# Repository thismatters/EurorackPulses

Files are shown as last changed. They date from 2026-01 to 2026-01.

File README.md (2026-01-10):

# Pulses Expander (for Turing Machine)

The circuit here is a direct copy of the [Music Thing Modular Volts Expander](https://github.com/TomWhitwell/Turing-Pulse-Expander).

The KiCAD project here uses the library/footprints [found in my companion repo](https://github.com/thismatters/EurorackKiCAD).

## Width

6hp

## Inputs

The back of the module has a connection for the `pulses` output from the Turing Machine.

## Outputs

11 jacks which pulse along with the bits (and combinations thereof) on the Turing Machine.

## Vendors

There are part numbers in the [BOM](tm-pulses.csv) for many of the parts (not for basic passives though) at the following vendors:

* [Mouser](https://www.mouser.com): Needs no introduction. Get your ICs from here (or [digikey](https://www.digikey.com)).
* [Tayda Electronics](https://www.taydaelectronics.com/): Good supplier for passive components; audio jacks, and potentiometers. Their audio jacks are slightly smaller than the thonkiconn from thonk.
* [Love My Switches](https://lovemyswitches.com/): Has [really good knobs](https://lovemyswitches.com/anodized-aluminum-knob-the-lo-fi-1-4-smooth-shaft-12-5mm-od/) to go on those potentiometers!
* [OSHPark](https://oshpark.com/): Fast and (relatively) cheap PCB manufacturer. Prototype run pending.

## Changelog

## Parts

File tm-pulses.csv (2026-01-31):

# | Reference | Qty | Value | Footprint | DNP | Vendor | PartNum | Note
1 | D1, D2, D3, D4, D5, D6, D7, D8, D9, D10, D11 | 11 | LED_GREEN | LED_THT:LED_D3.0mm
2 | J1 | 1 | Conn_02x08_Odd_Even | Eurorack:PinHeader_2x08_P2.54mm_Vertical |  | Tayda | A-2956
3 | J2 | 1 | OUT1 | Eurorack:AudioJack2_Tayda_A-2566 |  | Tayda | A-2566
4 | J3 | 1 | OUT2 | Eurorack:AudioJack2_Tayda_A-2566 |  | Tayda | A-2566
5 | J4 | 1 | OUT3 | Eurorack:AudioJack2_Tayda_A-2566 |  | Tayda | A-2566
6 | J5 | 1 | OUT4 | Eurorack:AudioJack2_Tayda_A-2566 |  | Tayda | A-2566
7 | J6 | 1 | OUT5 | Eurorack:AudioJack2_Tayda_A-2566 |  | Tayda | A-2566
8 | J7 | 1 | OUT6 | Eurorack:AudioJack2_Tayda_A-2566 |  | Tayda | A-2566
9 | J8 | 1 | OUT7 | Eurorack:AudioJack2_Tayda_A-2566 |  | Tayda | A-2566
10 | J9 | 1 | OUT12 | Eurorack:AudioJack2_Tayda_A-2566 |  | Tayda | A-2566
11 | J10 | 1 | OUT24 | Eurorack:AudioJack2_Tayda_A-2566 |  | Tayda | A-2566
12 | J11 | 1 | OUT47 | Eurorack:AudioJack2_Tayda_A-2566 |  | Tayda | A-2566
13 | J12 | 1 | OUT1247 | Eurorack:AudioJack2_Tayda_A-2566 |  | Tayda | A-2566
14 | R1, R3, R5, R7, R9, R11, R13, R15, R17, R19, R21 | 11 | 1K | Resistor_SMD:R_0805_2012Metric
15 | R2, R4, R6, R8, R10, R12, R14, R16, R18, R20, R22 | 11 | 2K | Resistor_SMD:R_0805_2012Metric
16 | U1 | 1 | 4081 | Package_SO:TSSOP-14_4.4x5mm_P0.65mm |  | Mouser | 595-CD4081BPWR

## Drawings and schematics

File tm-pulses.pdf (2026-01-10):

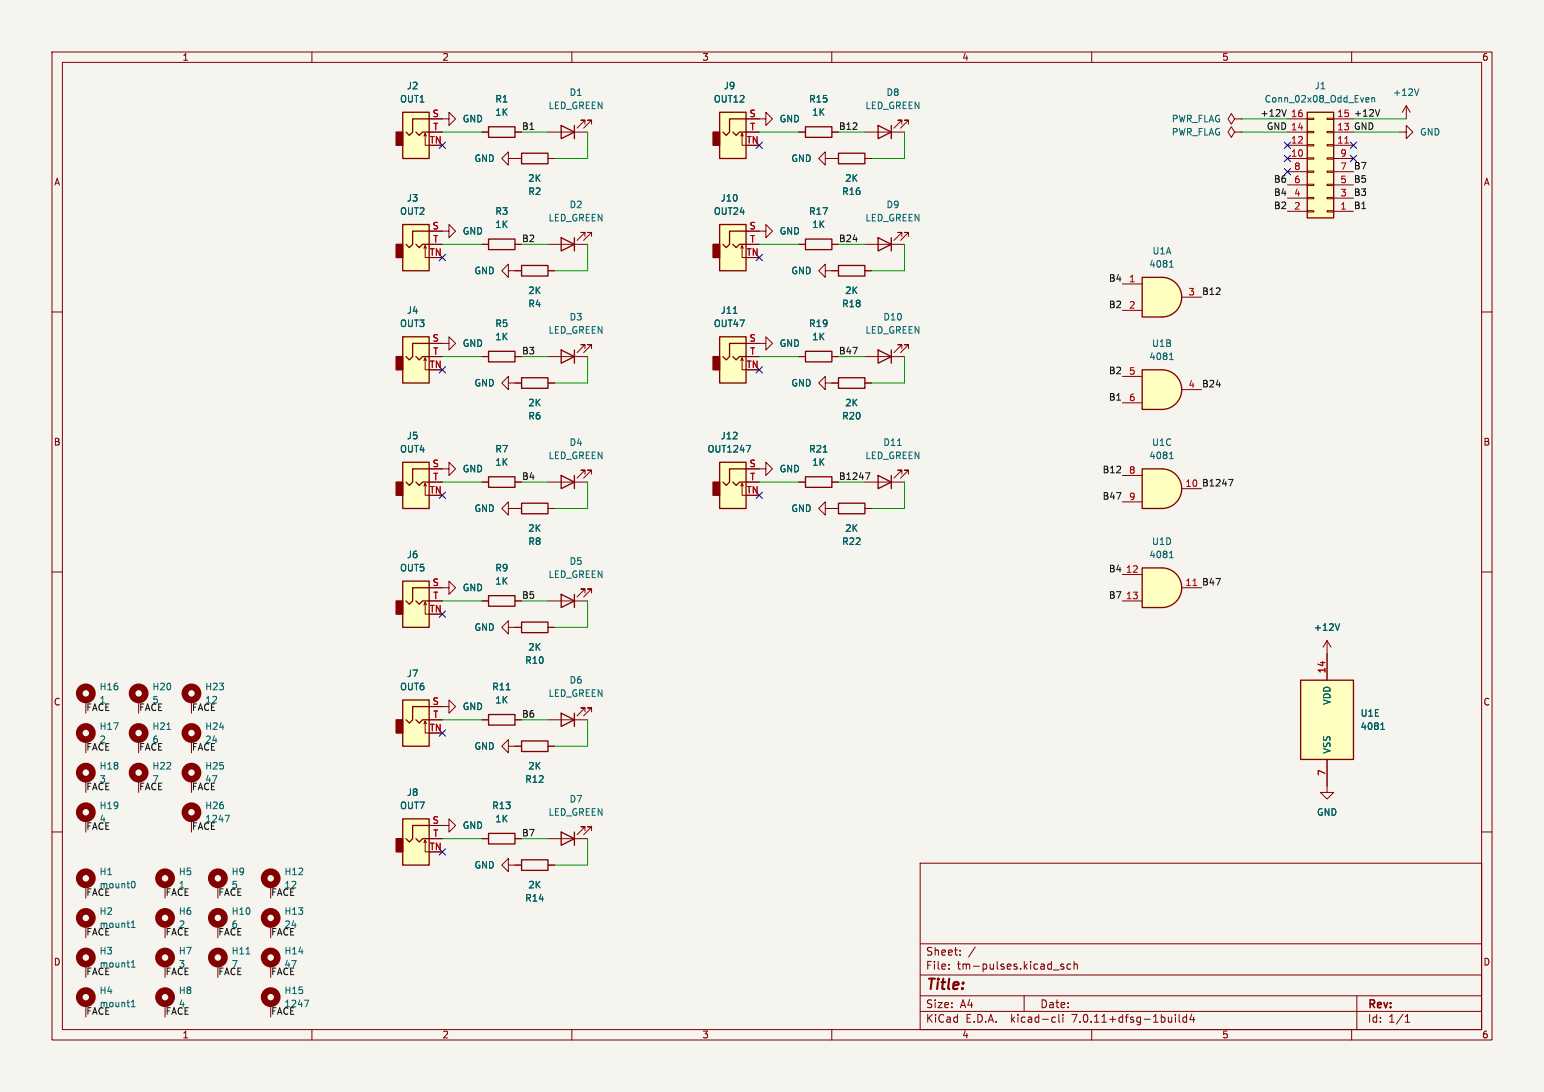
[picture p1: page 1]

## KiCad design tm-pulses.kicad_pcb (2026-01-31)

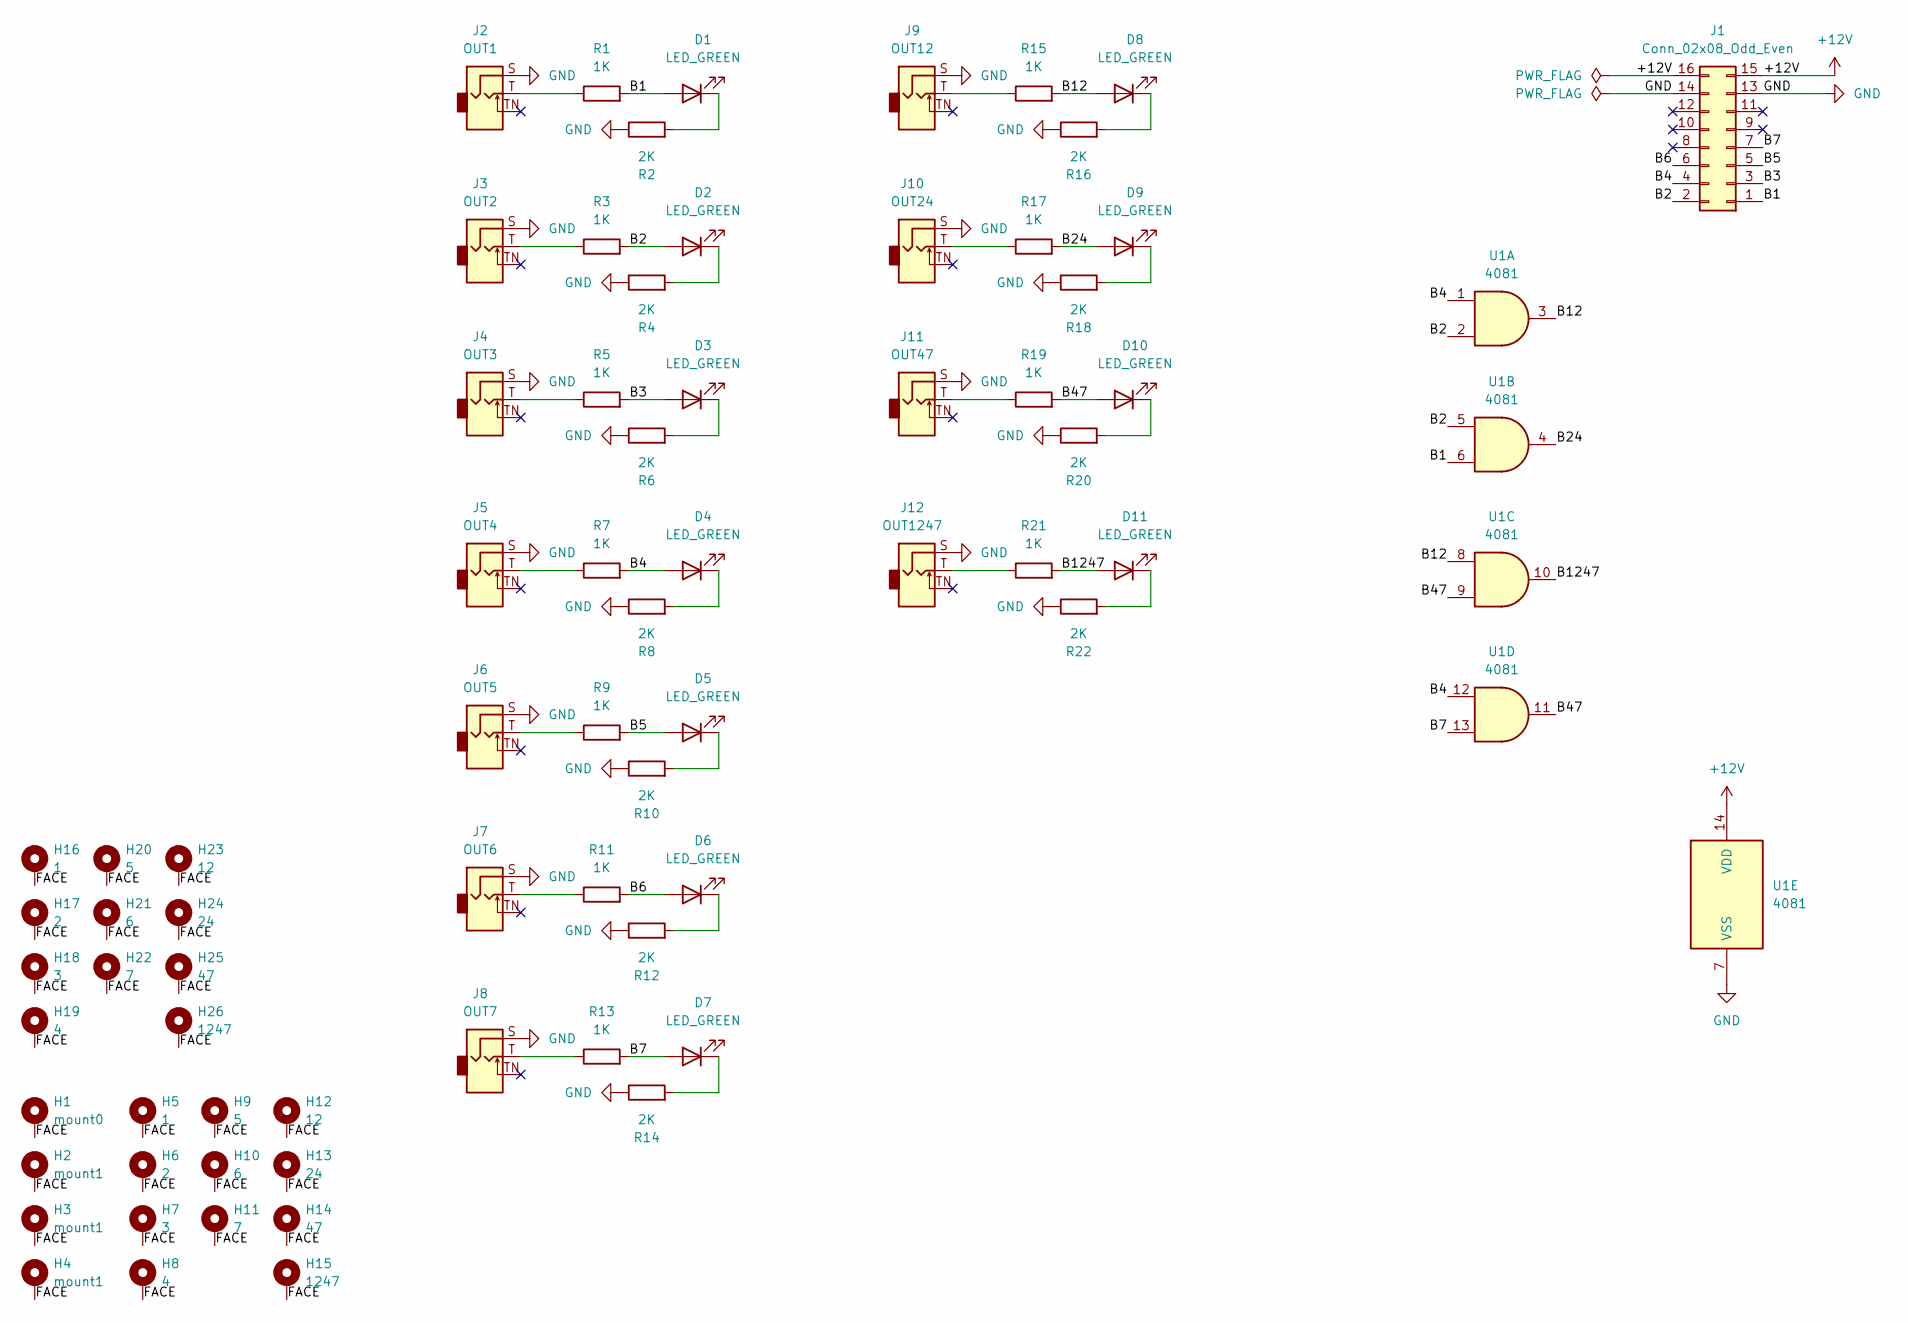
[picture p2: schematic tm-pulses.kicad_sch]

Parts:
D1, D2, D3, D4, D5, D6, D7, D8, D9, D10, D11: LED_GREEN; LED_D3.0mm
H1: mount0; Mech-MountingHole
H2, H3, H4: mount1; Mech-MountingHole
H5: 1; Mech-AudioJack-Hole-Output-Gate
H6: 2; Mech-AudioJack-Hole-Output-Gate
H7: 3; Mech-AudioJack-Hole-Output-Gate
H8: 4; Mech-AudioJack-Hole-Output-Gate
H9: 5; Mech-AudioJack-Hole-Output-Gate
H10: 6; Mech-AudioJack-Hole-Output-Gate
H11: 7; Mech-AudioJack-Hole-Output-Gate
H12: 12; Mech-AudioJack-Hole-Output-Gate
H13: 24; Mech-AudioJack-Hole-Output-Gate
H14: 47; Mech-AudioJack-Hole-Output-Gate
H15: 1247; Mech-AudioJack-Hole-Output-Gate
H16: 1; Mech-LED-Hole-3mm
H17: 2; Mech-LED-Hole-3mm
H18: 3; Mech-LED-Hole-3mm
H19: 4; Mech-LED-Hole-3mm
H20: 5; Mech-LED-Hole-3mm
H21: 6; Mech-LED-Hole-3mm
H22: 7; Mech-LED-Hole-3mm
H23: 12; Mech-LED-Hole-3mm
H24: 24; Mech-LED-Hole-3mm
H25: 47; Mech-LED-Hole-3mm
H26: 1247; Mech-LED-Hole-3mm
J1: Conn_02x08_Odd_Even; PinHeader_2x08_P2.54mm_Vertical; PartNum A-2956
J2: OUT1; AudioJack2_Tayda_A-2566; PartNum A-2566
J3: OUT2; AudioJack2_Tayda_A-2566; PartNum A-2566
J4: OUT3; AudioJack2_Tayda_A-2566; PartNum A-2566
J5: OUT4; AudioJack2_Tayda_A-2566; PartNum A-2566
J6: OUT5; AudioJack2_Tayda_A-2566; PartNum A-2566
J7: OUT6; AudioJack2_Tayda_A-2566; PartNum A-2566
J8: OUT7; AudioJack2_Tayda_A-2566; PartNum A-2566
J9: OUT12; AudioJack2_Tayda_A-2566; PartNum A-2566
J10: OUT24; AudioJack2_Tayda_A-2566; PartNum A-2566
J11: OUT47; AudioJack2_Tayda_A-2566; PartNum A-2566
J12: OUT1247; AudioJack2_Tayda_A-2566; PartNum A-2566
R1, R3, R5, R7, R9, R11, R13, R15, R17, R19, R21: 1K; R_0805_2012Metric
R2, R4, R6, R8, R10, R12, R14, R16, R18, R20, R22: 2K; R_0805_2012Metric
U1: 4081; TSSOP-14_4.4x5mm_P0.65mm; PartNum 595-CD4081BPWR

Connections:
+12V: J1.15, J1.16, U1.14 (VDD)
/B1: D1.2 (A), J1.1, R1.2, U1.6
/B2: D2.2 (A), J1.2, R3.2, U1.2, U1.5
/B3: D3.2 (A), J1.3, R5.2
/B4: D4.2 (A), J1.4, R7.2, U1.1, U1.12
/B5: D5.2 (A), J1.5, R9.2
/B6: D6.2 (A), J1.6, R11.2
/B7: D7.2 (A), J1.7, R13.2, U1.13
/B12: D8.2 (A), R15.2, U1.3, U1.8
/B24: D9.2 (A), R17.2, U1.4
/B47: D10.2 (A), R19.2, U1.9, U1.11
/B1247: D11.2 (A), R21.2, U1.10
/FACE: H1.1, H2.1, H3.1, H4.1, H5.1, H6.1, H7.1, H8.1, H9.1, H10.1, H11.1, H12.1, H13.1, H14.1, H15.1, H16.1, H17.1, H18.1, H19.1, H20.1, H21.1, H22.1, H23.1, H24.1, H25.1, H26.1
GND: J1.13, J1.14, J2.S, J3.S, J4.S, J5.S, J6.S, J7.S, J8.S, J9.S, J10.S, J11.S, J12.S, R2.1, R4.1, R6.1, R8.1, R10.1, R12.1, R14.1, R16.1, R18.1, R20.1, R22.1, U1.7 (VSS)
unnamed: D1.1 (K), R2.2
unnamed: D2.1 (K), R4.2
unnamed: D3.1 (K), R6.2
unnamed: D4.1 (K), R8.2
unnamed: D5.1 (K), R10.2
unnamed: D6.1 (K), R12.2
unnamed: D7.1 (K), R14.2
unnamed: D8.1 (K), R16.2
unnamed: D9.1 (K), R18.2
unnamed: D10.1 (K), R20.2
unnamed: D11.1 (K), R22.2
unnamed: J2.T, R1.1
unnamed: J3.T, R3.1
unnamed: J4.T, R5.1
unnamed: J5.T, R7.1
unnamed: J6.T, R9.1
unnamed: J7.T, R11.1
unnamed: J8.T, R13.1
unnamed: J9.T, R15.1
unnamed: J10.T, R17.1
unnamed: J11.T, R19.1
unnamed: J12.T, R21.1

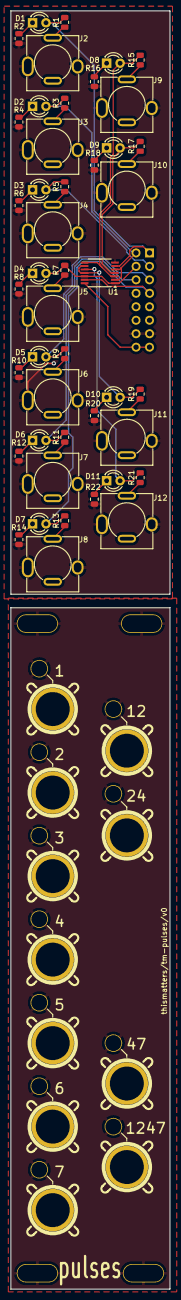
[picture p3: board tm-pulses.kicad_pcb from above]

Board: 2 copper layers, 30.0 x 241.0 mm, 72 parts (1 on the bottom side), 36 nets.

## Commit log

2026-01-10 initial commit (v0 ready)
    [tm-pulses.csv, tm-pulses.kicad_pcb, tm-pulses.kicad_sch]
2026-01-10 adding schematic
2026-01-31 prefab checklist v0
    [tm-pulses.csv, tm-pulses.kicad_pcb]
